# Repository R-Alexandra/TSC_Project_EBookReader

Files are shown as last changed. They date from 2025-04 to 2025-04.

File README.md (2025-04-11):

# TSC_Project_EBookReader - Rădulescu Alexandra

Acest proiect reprezintă un sistem de tip **eBook Reader** bazat pe microcontrolerul **ESP32-C6**, ce integrează module de stocare, afișare, senzori de mediu, alimentare prin baterie și interfețe de conectivitate. Dispozitivul este proiectat pentru un consum energetic scăzut și este compatibil cu multiple tipuri de afișaje E-Ink.

OpenBook_EBookReader_Update

---
## Diagramă Bloc
Diagrama_Bloc

---

## Bill of Materials (BOM)

| Componentă | Link Achiziționare | Link Datasheet |
|---|---|---|
| 112A-TAAR-R03 ATTEND | https://store.comet.srl.ro/Catalogue/Product/43497/ | https://www.snapeda.com/parts/112A-TAAR-R03/Attend/datasheet/ |
| Condensator C0402 | https://ro.mouser.com/c/passive-components/capacitors/ceramic-capacitors/?q=CC0402 | https://componentsearchengine.com/Datasheets/2/CC0402MRX5R5BB106.pdf |
| Condensator Tantalum | https://ro.mouser.com/ProductDetail/KYOCERA-AVX/TAJW107M010RNJ?qs=Wtp%252Bf%2FAeVqIH8v1VxV%252B1Rg%3D%3D | https://ro.mouser.com/datasheet/2/40/TAJ-3165264.pdf |
| CHG_LED | https://ro.mouser.com/ProductDetail/Kingbright/KP-1608SURCK?qs=2JU0tDl2GZ3FuyEWfBV1%2Fg== | https://www.snapeda.com/parts/KP-1608SURCK/Kingbright/datasheet/ |
| USBLC6-2SC6Y | https://ro.mouser.com/ProductDetail/STMicroelectronics/USBLC6-2SC6Y?qs=gNDSiZmRJS%2FOgDexvXkdow%3D%3D | https://ro.mouser.com/datasheet/2/389/usblc6_2sc6y-1852505.pdf |
| SD0805S020S1R0 | https://ro.mouser.com/ProductDetail/KYOCERA-AVX/SD0805S020S1R0?qs=jCA%252BPfw4LHbpkAoSnwrdjw%3D%3D | https://ro.mouser.com/datasheet/2/40/schottky-3165252.pdf |
| MBR0530 | https://ro.mouser.com/ProductDetail/onsemi-Fairchild/MBR0530?qs=VOMQJJE%252BBNniwJKcE3T43Q== | https://ro.mouser.com/datasheet/2/308/MBR0530_D-1810985.pdf |
| PGB1010603MR | https://www.digikey.com/en/products/detail/littelfuse-inc/PGB1010603MR/715755 | https://www.littelfuse.com/assetdocs/pulseguard-esd-suppressors-pgb1-datasheet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 |
| Rezistență R0402 | https://ro.mouser.com/c/passive-components/resistors/smd-resistors-chip-resistors/?case%20code%20-%20in=0402 | https://www.yageo.com/upload/media/product/products/datasheet/rchip/PYu-RC_Group_51_RoHS_L_12.pdf |
| BME680 | https://ro.mouser.com/ProductDetail/Bosch-Sensortec/BME688?qs=IS%252B4QmGtzzqQoVDscqwx3A%3D%3D | https://ro.mouser.com/datasheet/2/783/bst_bme688_fl000-2307034.pdf |
| W25Q512JVEIQ | https://ro.mouser.com/ProductDetail/Winbond/W25Q512JVEIQ?qs=l7cgNqFNU1jw6svr3at6tA%3D%3D | https://ro.mouser.com/datasheet/2/949/Winbond_W25Q512JV_Datasheet-3240039.pdf |
| ESP32-C6-WROOM-1-N8 | https://ro.mouser.com/ProductDetail/Espressif-Systems/ESP32-C6-WROOM-1-N8?qs=8Wlm6%252BaMh8ST02Gmwp74cw%3D%3D | https://ro.mouser.com/datasheet/2/891/Espressif_ESP32_C6_WROOM_1__Datasheet_V0_1_PRELIMI-3239987.pdf |
| DS3231SN# | https://ro.mouser.com/ProductDetail/Analog-Devices-Maxim-Integrated/DS3231SN?qs=1eQvB6Dk1vhUlr8%2FOrV0Fw%3D%3D | https://ro.mouser.com/datasheet/2/609/DS3231-3421123.pdf |
| MAX17048G+T10 | https://ro.mouser.com/ProductDetail/Analog-Devices-Maxim-Integrated/MAX17048G%2bT10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 | https://ro.mouser.com/datasheet/2/609/MAX17048_MAX17049-3469099.pdf |
| MCP73831 | https://ro.mouser.com/ProductDetail/Microchip-Technology/MCP73831T-2ATI-OT?qs=yUQqVecv4qsZbioEUu%252B83g%3D%3D | https://ro.mouser.com/datasheet/2/268/MCP73831_Family_Data_Sheet_DS20001984H-3441711.pdf |
| BD5229G-TR | https://www.digikey.com/en/products/detail/rohm-semiconductor/BD5229G-TR/3663792 | https://fscdn.rohm.com/en/products/databook/datasheet/ic/power/voltage_detector/bd52xxg-e.pdf |
| XC6220A331MR-G | https://ro.mouser.com/ProductDetail/Torex-Semiconductor/XC6220A331MR-G?qs=AsjdqWjXhJ8ZSWznL1J0gg%3D%3D | https://ro.mouser.com/datasheet/2/760/xc6220-3371556.pdf |
| FH34SRJ-24S-0.5SH(99) | https://ro.mouser.com/ProductDetail/Hirose-Connector/FH34SRJ-24S-0.5SH99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 | https://ro.mouser.com/datasheet/2/185/FH34SRJ_24S_0_5SH_99__CL0580_1255_6_99_2DDrawing_0-1615044.pdf |
| USB4110-GF-A | https://ro.mouser.com/ProductDetail/GCT/USB4110-GF-A?qs=KUoIvG%2F9IlYiZvIXQjyJeA%3D%3D | https://ro.mouser.com/datasheet/2/837/GCT_USB4110_Product_Drawing___20k_cycles-3455479.pdf |
| QWIIC_RIGHT_ANGLE | https://ro.mouser.com/ProductDetail/SparkFun/PRT-14417?qs=wd5RIQLrsJhgdz%2FpmZ%2F3GQ== | https://ro.mouser.com/datasheet/2/813/Qwiic_Connector_Datasheet-1223982.pdf |
| Bobină 744043680 | https://ro.mouser.com/ProductDetail/Wurth-Elektronik/744043680?qs=PGXP4M47uW6VkZq%252BkzjrHA%3D%3D | https://www.we-online.com/components/products/datasheet/744043680.pdf |
| PFMF.050.1 | https://ro.mouser.com/ProductDetail/EPCOS-TDK/B72520T0350K062?qs=dEfas%2FXlABIszF52uu7vrg%3D%3D | https://www.tdk-electronics.tdk.com/inf/75/db/CTVS_14/Surge_protection_series.pdf |
| DMG2305UX-7 | https://www.digikey.com/en/products/detail/diodes-incorporated/DMG2305UX-7/4340666 | https://www.diodes.com/assets/Datasheets/DMG2305UX.pdf |
| Si1308EDL-T1-GE3 | https://www.digikey.com/en/products/detail/vishay-siliconix/SI1308EDL-T1-GE3/4876435 | https://www.vishay.com/docs/63399/si1308edl.pdf |
| Solder Jumper (SJ) | https://grabcad.com/library/solder-jumpers-1 | https://grabcad.com/library/solder-jumpers-1 |
| Buton | https://industry.panasonic.com/global/en/products/control/switch/light-touch/number/evqpuj02k | https://industry.panasonic.com/global/en/downloads?tab=catalog&small_g_cd=203&part_no=EVQPUJ02K |
| CPH3225A | https://www.digikey.com/en/products/detail/seiko-instruments/CPH3225A/8692444 | https://mm.digikey.com/Volume0/opasdata/d220001/medias/docus/6537/rev05-CPHCPM.pdf |

---

## Descriere a componentelor și funcționalității hardware

OpenBook_PCB_3D_top_Update

### Microcontroller: ESP32-C6

- Microcontroller RISC-V pe 32 de biți cu suport **Wi-Fi 6** și **Bluetooth 5 Low Energy (BLE)**
- Alimentat la **3.3V**
- Gestionează toate perifericele proiectului
- Oferă multiple interfețe  **GPIO, SPI, I2C, UART**
  - **SPI**(Serial Peripheral Interface): pentru conectare la memoria NOR Flash, cardul SD și afișajul E-Ink
  - **I2C**(Inter-Integrated Circuit): pentru conectare la senzorul BME688, modulul RTC DS3231 și senzorul de nivel baterie MAX17048
  - **GPIO**(General Purpose Input/Output): utilizat pentru semnale de control pentru ecranul E-Ink, butoane și detecție SD
- Are o arhitectură optimizată pentru **consum redus de energie**, ideală pentru aplicații portabile

### Alimentare și protecție

#### Regulator de tensiune LDO

- **XC6206P332MR-G** transformă tensiunea VIN (5V) în 3.3V și  este folosit un tranzistor suplimentar pentru controlul alimentării

#### Controller de încărcare baterie

- **MCP73831** gestionează încărcarea bateriei Li-Po 3.7V cu protecție integrată contra supratensiunii și a curentului excesiv
- LED-uri pentru semnalizare stare de încărcare

#### Monitorizare nivel baterie

- **MAX17048** oferă monitorizare în timp real a stării de încărcare a bateriei 
- Comunică cu ESP32-C6 prin interfața I2C

#### Conector USB-C și protecție ESD

- Conector **USB-C** pentru alimentare și comunicație
- Protecție la descărcări electrostatice realizată prin **PMF0501** și **USBLC6-2SC6Y**, care protejează liniile de alimentare și semnal

## Stocare

### Card microSD

- Conectat la magistrala **SPI**
- Permite stocarea fișierelor eBook și a jurnalelor de sistem
- Linie dedicată pentru **detectare automată** a cardului

### Memorie NOR Flash externă (64MB)

- Chipul **W25Q512JVEIQ** furnizeză memorie nevolatilă pentru firmware și resurse statice
- Conectată la magistrala **SPI**

## Afișaj E-Paper

### Interfață EPD dedicată

- Include toate conexiunile necesare pentru controlul unui ecran E-Ink (**SPI**, semnale de control precum **EPD_BUSY, EPD_DC, EPD_RST** etc).
- Header dedicat EPD cu 20 pini, compatibil cu mai multe modele DE afișaje.

### Circuit de alimentare EPD

- Utilizează un convertor DC-DC și tranzistoare MOSFET pentru a genera tensiunile de alimentare cerute de ecranele E-Ink.

### Selector tip afișaj

- Permite alegerea tipului de ecran conectat, în funcție de compatibilitatea cu semnalele de control.

## Senzor BME680

- Măsoară: **temperatură, umiditate, presiune atmosferică, calitate aer (VOCs)**
- Este conectat prin interfața **I2C** (SDA și SCL)

## Modul RTC (DS3231SN)

- Precizie ridicată pentru a păstra ora și data corectă, chiar și în absența alimentării principale.
- Interfață **I2C** (SDA și SCL)

## Butoane de control

- Buton **RESET**
- Buton **BOOT**
- Buton custom **IO/CHANGE**

## Test Pads și Conectori de extensie

- Sunt prezente **paduri de testare** și debugging 
- Conector **Qwiic/Stemma QT** pentru extinderea rapidă a sistemului cu senzori I2C suplimentari

## Protecție ESD pentru SPI

- Liniile **SPI** sunt protejate împotriva descărcărilor electrostatice

---

## Consum estimativ de energie
Sistemul este proiectat pentru un consum energetic redus, aspect esențial pentru funcționarea pe baterie.

| Componentă | Consum estimativ |
|---|---|
| ESP32-C6 (Wi-Fi activ) | 120 – 150 mA |
| Afișaj EPD | 20 – 40 mA |
| Senzor BME688 | 1 – 2 mA |
| Card SD (scriere/citire)| 50 – 100 mA |
| MAX17048 + RTC DS3231 | < 1 mA |
| **Total (mod activ)** | **~300 mA** |
| **Total (deep sleep)** | **< 10 mA** |

### Estimare autonomie (baterie LiPo 2000mAh):
- **Folosire intensivă**: câteva ore
- **Standby cu afiș static**: zile/săptămâni

---

## Alocarea pinilor ESP32-C6

### 1. Afișaj EPD (e-paper display)

| Pin ESP32-C6 | Funcție | Observație |
|---|---|---|
| IO3 (26) | EPD_BUSY | Verifică dacă ecranul este ocupat |
| IO5 (5) | EPD_DC | Comută între date și comandă |
| IO6 (6) | SCK | Linie de ceas SPI |
| IO7 (7) | MOSI | Transmisie date SPI |
| IO10 (11) | EPD_CS | Selectare chip pentru EPD |
| IO23 (21) | EPD_RST | Resetare ecran |
| IO20 (18) | EPD_3V3_C | Control alimentare 3V3 pentru EPD |

### 2. Card SD

| Pin ESP32-C6 | Funcție | Observație |
|---|---|---|
| IO2 (27) | MISO | Recepție date SPI |
| IO4 (4) | SS_SD | Selectare chip SD |
| IO6 (6) | SCK | Linie de ceas SPI |
| IO7 (7) | MOSI | Transmisie date SPI |

### 3. Memorie Flash NOR

| Pin ESP32-C6 | Funcție | Observație |
|---|---|---|
| IO11 (12) | FLASH_CS | Selectare chip Flash |
| IO2 (27) | MISO | Recepție date SPI |
| IO6 (6) | SCK | Linie de ceas SPI |
| IO7 (7) | MOSI | Transmisie date SPI |

### 4. Magistrală I2C (BME688, RTC DS3231, MAX17048)

| Pin ESP32-C6 | Funcție | Observație |
|---|---|---|
| IO21 (19) | SDA | Linie de date I2C |
| IO22 (20) | SCL | Linie de ceas I2C |
| IO19 (17) | I2C_PW | Activare alimentare senzori I2C |

### 5. RTC (DS3231)

| Pin ESP32-C6 | Funcție | Observație |
|---|---|---|
| IO0 (8) | INT_RTC | Semnal de întrerupere |
| IO1 (9) | 32KHz | Ieșire ceas precis |
| IO18 (16) | RTC_RST | Reset hardware RTC |

### 6. Conectivitate USB

| Pin ESP32-C6 | Funcție | Observație |
|---|---|---|
| IO12 (13) | USB_D- | Comunicație USB |
| IO13 (14) | USB_D+ | Comunicație USB |

### 7. Serială UART 

| Pin ESP32-C6 | Funcție | Observație |
|---|---|---|
| IO16 (25) | TX | Transmisie UART |
| IO17 (24) | RX | Recepție UART |

### 8. Butoane 

| Pin ESP32-C6 | Funcție | Observație |
|---|---|---|
| EN (3) | RESET | Reset general microcontroler |
| IO8 (10) | IO/BOOT | Buton BOOT (pus pe GND la pornire)  |
| IO15 (23) | IO/CHANGE | Buton custom |

### 9. Alimentare și Referință

| Pin ESP32-C6 | Funcție | Observație |
|---|---|---|
| Pin 2 | 3V3 | Alimentare principală |
| Pin 1 | GND | Împământare |

---

## Considerații privind realizarea proiectului
În procesul de realizare a designului hardware am respectat cerințele din ghidurile de proiectare (ERC, DRC, layout) și am încercat să iau decizii care să ofere echilibru între funcționalitate, integrare și respectarea bunelor practici. Amplasarea componentelor am făcut-o atât pe baza documentației oferite (dimensiuni mecanice și recomandări de placement), cât și pentru o rutare cât mai bună, care să reducă interferențele și să faciliteze traseele de alimentare și semnal.

Pentru designul PCB-ului, am folosit DRC-ul oferit pentru verificare și am rezolvat erorile apărute, inclusiv prin ajustarea dimensiunii unor footprint-uri. Am aplicat regulile de rutare pentru traseele de putere și pentru date, evitând unghiurile drepte. Traseele de alimentare au lățimea de 0.3mm, restul traseelor de 0.15mm și am realizat câte un plan de masă atât pentru top cât și pe bottom. Test pad-urile rămase le-am poziționat astfel încât să putem testa rapid anumite componente: 
- lângă header-ul display-ului pentru a testa alimentarea și semnalele de date către ecran;
- lângă ESP32-C6 pentru a verifica semnale critice și pentru debugging.

Am avut în vedere și integrarea finală în ansamblul 3D al carcasei. De aceea, am poziționat conectorii astfel încât să fie accesibili din exterior, iar unele componente au fost ușor translatate pentru a obține o potrivire corectă și o funcționare bună a dispozitivului. De asemenea, am desenat bateria și ecranul folosind dimensiunile mecanice specificate pentru o integrare cât mai bună.

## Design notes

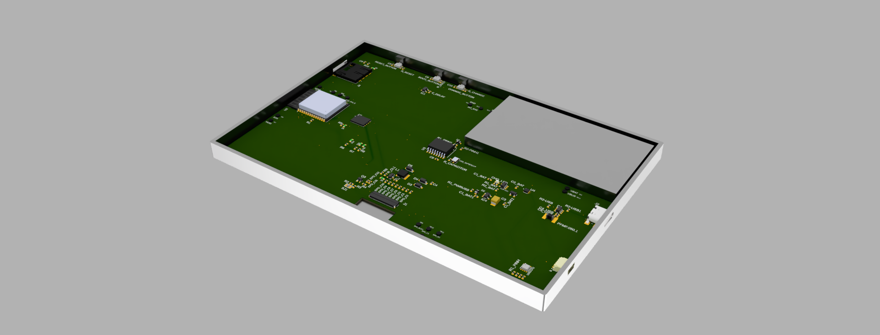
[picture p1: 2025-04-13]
Images/OpenBook_EBookReader_open.png

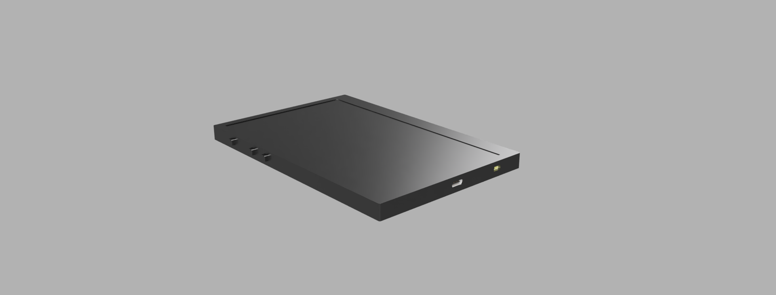
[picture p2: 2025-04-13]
Images/OpenBook_EBookReader_Update.png

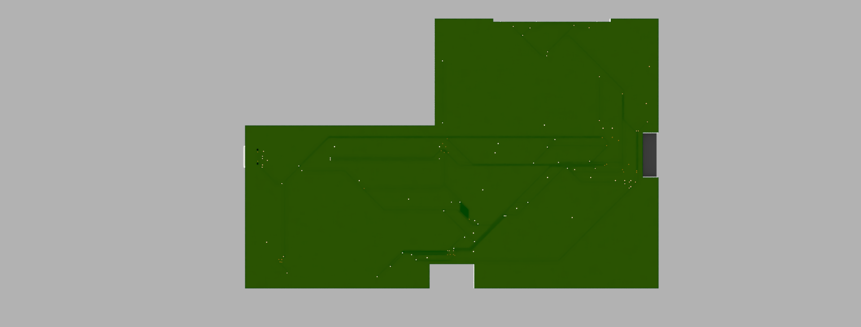
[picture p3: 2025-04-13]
Images/OpenBook_PCB_3D_bottom_Update.PNG

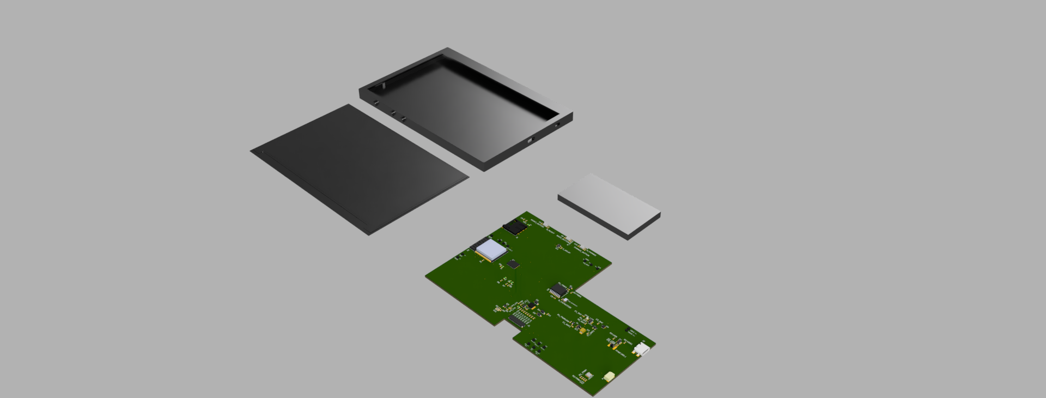
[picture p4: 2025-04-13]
Images/OpenBook_EBookReader_ExplodedView_Update.PNG

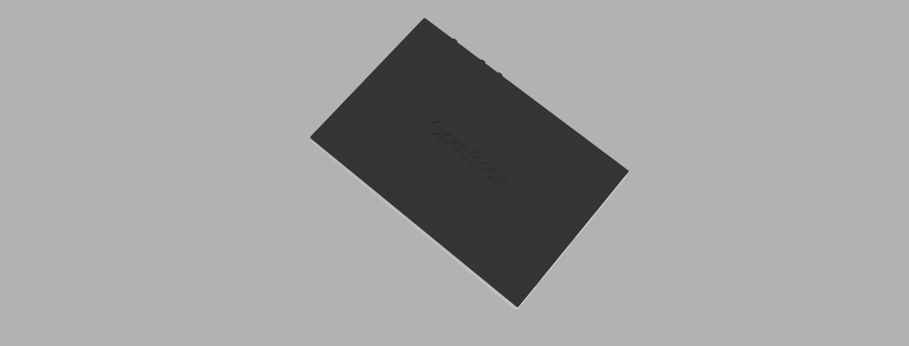
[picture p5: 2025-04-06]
Images/OpenBook_EBookReader2.jpg

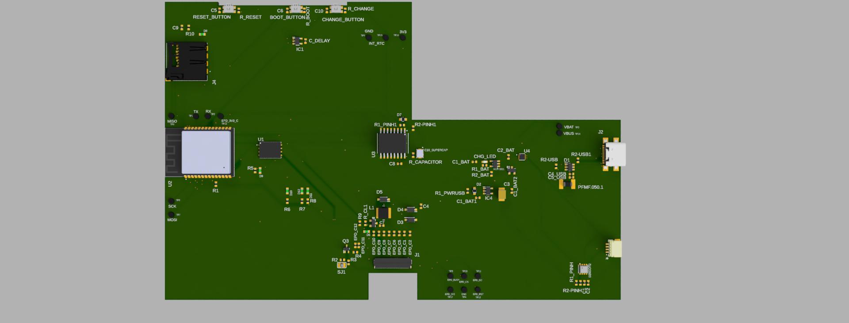
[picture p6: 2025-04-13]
Images/OpenBook_PCB_3D_top_Update.jpg

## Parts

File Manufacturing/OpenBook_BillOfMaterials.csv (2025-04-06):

Qty | Value | Device | Package | Parts | Description | ARROW_PART_NUMBER | ARROW_PRICE-STOCK | AVAILABILITY | CENTROID_NOT_SPECIFIED | CHECK_PRICES | COPYRIGHT | DATASHEET | DESCRIPTION | DIGIKEY_DESCRIPTION | DIGIKEY_PART_NUMBER | HEIGHT | LEAD_FREE | MANUFACTURER_NAME | MANUFACTURER_PART_NUMBER | MF | MFR_NAME | MOUSER_PART_NUMBER | MOUSER_PRICE-STOCK | MOUSER_TESTING_PART_NUMBER | MOUSER_TESTING_PRICE-STOCK | MP | MPN | PACKAGE | POPULARITY | PREFIX | PRICE | PROD_ID | PURCHASE-URL | ROHS | SNAPEDA_LINK | SPICEMODEL | SPICEPREFIX | TEMPERATURE_RANGE_HIGH | TEMPERATURE_RANGE_LOW | TP_SIGNAL_NAME | VALUE
1 |  | ADAFRUIT_LEDCHIP-LED0603 | ADAFRUIT_CHIP-LED0603 | CHG_LED | LED
1 |  | SJ | SJ | SJ1 | SMD solder JUMPER |  |  |  |  |  |  |  |  |  |  |  |  |  |  |  |  |  |  |  |  |  |  |  | 3
1 | 0.1uF/50V | ESP32_WROVER_EAGLE-LTSPICE_CC0402 | ESP32_WROVER_EAGLE-LTSPICE_C0402 | EPD_C5 | CAPACITOR, European symbol |  |  |  |  |  |  |  |  |  |  |  |  |  |  |  |  |  |  |  |  |  |  |  |  |  |  |  |  |  |  | NONE | C
1 | 0.47 | ESP32_WROVER_EAGLE-LTSPICE_RR0402 | ESP32_WROVER_EAGLE-LTSPICE_R0402 | R3 | RESISTOR, European symbol |  |  |  |  |  |  |  |  |  |  |  |  |  |  |  |  |  |  |  |  |  |  |  |  |  |  |  |  |  |  | NONE | R
1 | 100K | ESP32_WROVER_EAGLE-LTSPICE_RR0402 | ESP32_WROVER_EAGLE-LTSPICE_R0402 | R1_PWRUSB | RESISTOR, European symbol |  |  |  |  |  |  |  |  |  |  |  |  |  |  |  |  |  |  |  |  |  |  |  |  |  |  |  |  |  |  | NONE | R
8 | 100nF | ESP32_WROVER_EAGLE-LTSPICE_CC0402 | ESP32_WROVER_EAGLE-LTSPICE_C0402 | C1, C2, C4_USB, C6, C8, C9, C10, C_DELAY | CAPACITOR, European symbol |  |  |  |  |  |  |  |  |  |  |  |  |  |  |  |  |  |  |  |  |  |  |  |  |  |  |  |  |  |  | NONE | C
1 | 100uF TANT | RCL_CPOL-EUCT3528 | RCL_CT3528 | C3 | POLARIZED CAPACITOR, European symbol |  |  |  |  |  |  |  |  |  |  |  |  |  |  |  |  |  |  |  |  |  |  |  | 0 |  |  |  |  |  |  |  | C
16 | 10K | ESP32_WROVER_EAGLE-LTSPICE_RR0402 | ESP32_WROVER_EAGLE-LTSPICE_R0402 | R1, R1_PINH, R1_PINH1, R2-PINH, R2-PINH1, R4, R5, R6, R7, R8, R9, R10, R_BOOT, R_CHANGE, R_CL1, R_RESET | RESISTOR, European symbol |  |  |  |  |  |  |  |  |  |  |  |  |  |  |  |  |  |  |  |  |  |  |  |  |  |  |  |  |  |  | NONE | R
1 | 10uF | ESP32_WROVER_EAGLE-LTSPICE_CC0402 | ESP32_WROVER_EAGLE-LTSPICE_C0402 | C7 | CAPACITOR, European symbol |  |  |  |  |  |  |  |  |  |  |  |  |  |  |  |  |  |  |  |  |  |  |  |  |  |  |  |  |  |  | NONE | C
1 | 112A-TAAR-R03_ATTEND | 112A-TAAR-R03_ATTEND | 112ATAARR03ATTEND | J4 | Micro SD Card Socket, Push-Push Type, Top Mount, SMT, H=1.83mm, 10u |  |  |  |  |  |  |  | Micro SD Card Socket | Push-Push Type | Top Mount | SMT | H=1.83mm | 10u |  |  | 1.9mm |  | ATTEND | 112A-TAAR-R03 ATTEND
1 | 15 | ESP32_WROVER_EAGLE-LTSPICE_RR0402 | ESP32_WROVER_EAGLE-LTSPICE_R0402 | R_CAPACITOR | RESISTOR, European symbol |  |  |  |  |  |  |  |  |  |  |  |  |  |  |  |  |  |  |  |  |  |  |  |  |  |  |  |  |  |  | NONE | R
1 | 1uF | ESP32_WROVER_EAGLE-LTSPICE_CC0402 | ESP32_WROVER_EAGLE-LTSPICE_C0402 | C5 | CAPACITOR, European symbol |  |  |  |  |  |  |  |  |  |  |  |  |  |  |  |  |  |  |  |  |  |  |  |  |  |  |  |  |  |  | NONE | C
9 | 1uF/50V | ESP32_WROVER_EAGLE-LTSPICE_CC0402 | ESP32_WROVER_EAGLE-LTSPICE_C0402 | EPD_C1, EPD_C2, EPD_C6, EPD_C7, EPD_C8, EPD_C9, EPD_C10, EPD_C11, EPD_C12 | CAPACITOR, European symbol |  |  |  |  |  |  |  |  |  |  |  |  |  |  |  |  |  |  |  |  |  |  |  |  |  |  |  |  |  |  | NONE | C
1 | 2.2 | ESP32_WROVER_EAGLE-LTSPICE_RR0402 | ESP32_WROVER_EAGLE-LTSPICE_R0402 | R2 | RESISTOR, European symbol |  |  |  |  |  |  |  |  |  |  |  |  |  |  |  |  |  |  |  |  |  |  |  |  |  |  |  |  |  |  | NONE | R
1 | 200 | ESP32_WROVER_EAGLE-LTSPICE_RR0402 | ESP32_WROVER_EAGLE-LTSPICE_R0402 | R1_BAT | RESISTOR, European symbol |  |  |  |  |  |  |  |  |  |  |  |  |  |  |  |  |  |  |  |  |  |  |  |  |  |  |  |  |  |  | NONE | R
2 | 20V/4.2A/52m?/1.4W | ESP32_WROVER_SPARKFUN-DISCRETESEMI_MOSFET_PCH-DMG2305UX-7 | ESP32_WROVER_SPARKFUN-DISCRETESEMI_SOT23-3 | Q1, Q2 | P-channel MOSFETs |  |  |  |  |  |  |  |  |  |  |  |  |  |  |  |  |  |  |  |  |  |  |  |  |  |  | TRAN-14388 |  |  |  |  |  |  |  |  | 20V/4.2A/52m?/1.4W
1 | 2K | ESP32_WROVER_EAGLE-LTSPICE_RR0402 | ESP32_WROVER_EAGLE-LTSPICE_R0402 | R2_BAT | RESISTOR, European symbol |  |  |  |  |  |  |  |  |  |  |  |  |  |  |  |  |  |  |  |  |  |  |  |  |  |  |  |  |  |  | NONE | R
5 | 4.7uF | ESP32_WROVER_EAGLE-LTSPICE_CC0402 | ESP32_WROVER_EAGLE-LTSPICE_C0402 | C1_BAT, C1_BAT1, C1_BAT2, C2_BAT, C5_USB | CAPACITOR, European symbol |  |  |  |  |  |  |  |  |  |  |  |  |  |  |  |  |  |  |  |  |  |  |  |  |  |  |  |  |  |  | NONE | C
1 | 4.7uF/25V | ESP32_WROVER_EAGLE-LTSPICE_CC0402 | ESP32_WROVER_EAGLE-LTSPICE_C0402 | C4 | CAPACITOR, European symbol |  |  |  |  |  |  |  |  |  |  |  |  |  |  |  |  |  |  |  |  |  |  |  |  |  |  |  |  |  |  | NONE | C
2 | 5k1 | ESP32_WROVER_EAGLE-LTSPICE_RR0402 | ESP32_WROVER_EAGLE-LTSPICE_R0402 | R2-USB, R2-USB1 | RESISTOR, European symbol |  |  |  |  |  |  |  |  |  |  |  |  |  |  |  |  |  |  |  |  |  |  |  |  |  |  |  |  |  |  | NONE | R
1 | 68uH | 744043680IND_4828-WE-TPC_WRE | IND_4828-WE-TPC_WRE | L1 |  |  |  |  |  |  | Copyright (C) 2024 Ultra Librarian. All rights reserved. |  |  |  |  |  |  |  | 744043680 |  | Wurth Electronics
1 | BD5229G-TR | BD5229G-TR | SOT95P280X125-5N | IC1 | Voltage Detector with Adjustable Delay Time: CMOS processes are utilized to develop high precision, low current consumption CMOS reset ICs that allow arbitrary setting of the delay time. The extensive lineup includes both Nch Open Drain and CMOS output types in a wide range of detection voltages (from 2.3V to 6.0V, in 0.1V steps), enabling selection of the ideal solution based on customer requirements. In addition, the entire series is of course both lead-free and RoHS-compliant. |  |  |  |  |  |  |  | Voltage Detector with Adjustable Delay Time: CMOS processes are utilized to develop high precision | low current consumption CMOS reset ICs that allow arbitrary setting of the delay time. The extensive lineup includes both Nch Open Drain and CMOS output types in a wide range of detection voltages (from 2.3V to 6.0V | in 0.1V steps) | enabling selection of the ideal solution based on customer requirements. In addition | the entire series is of course both lead-free and RoHS-compliant. |  |  | 1.25mm |  | ROHM Semiconductor | BD5229G-TR |  |  | 755-BD5229G-TR | https://www.mouser.co.uk/ProductDetail/ROHM-Semiconductor/BD5229G-TR?qs=4kLU8WoGk0vvnhrrYwdszw%3D%3D
1 | BME688 | ESP32_WROVER_BME680_BME680 | ESP32_WROVER_BME680_PSON80P300X300X100-8N | SENSOR2 | Integrated Environmental Unit |  |  | Unavailable |  |  |  |  | Integrated Environmental Unit |  |  |  |  |  |  | Bosch Sensortec |  |  |  |  |  | BME680 |  | LGA-8 Bosch Tools |  |  | None
3 | BUTTON_CUSYOMV1 | BUTTON_CUSYOMV1 | MYBUTTON | BOOT_BUTTON, CHANGE_BUTTON, RESET_BUTTON
1 | CPH3225A | CPH3225A | CAPCP3225X100N | C10_SUPERCAP | Cap 0.011F 3.3V 1210 Flat Check availability |  |  | Not in stock |  | https://www.snapeda.com/parts/CPH3225A/Seiko+Instruments/view-part/?ref=eda |  |  | 11 mF (EDLC) Supercapacitor 3.3 V 1210 (3225 Metric) - - |  |  |  |  |  |  | Seiko Instruments |  |  |  |  |  | CPH3225A |  | 1210 Seiko |  |  | None |  | https://www.snapeda.com/api/url_track_click_mouser/?unipart_id=562593&manufacturer=Seiko Instruments&part_name=CPH3225A&search_term=None |  | https://www.snapeda.com/parts/CPH3225A/Seiko+Instruments/view-part/?ref=snap
1 | DS3231SN# | DS3231SN# | SOIC127P1032X265-16N | U3 | Real Time Clock Serial 16-Pin SOIC W T/R Check availability |  |  | In Stock |  | https://www.snapeda.com/parts/DS3231SN%23/Analog+Devices/view-part/?ref=eda |  |  | Extremely Accurate I2C-Integrated RTC/TCXO/Crystal |  |  |  |  |  |  | Analog Devices |  |  |  |  |  | DS3231SN# |  | SOIC-16 Maxim |  |  | None |  | https://www.snapeda.com/api/url_track_click_mouser/?unipart_id=99048&manufacturer=Analog Devices&part_name=DS3231SN#&search_term=None |  | https://www.snapeda.com/parts/DS3231SN%23/Analog+Devices/view-part/?ref=snap
1 | ESP32-C6-WROOM-1-N8 | ESP32-C6-WROOM-1-N8 | XCVR_ESP32-C6-WROOM-1-N8 | U2 | Check availability |  |  | In Stock |  | https://www.snapeda.com/parts/ESP32-C6-WROOM-1-N8/Espressif+Systems/view-part/?ref=eda |  |  | Multiprotocol Modules ESP32-C6 module | Wi-Fi 6 in 2.4 GHz band | Bluetooth 5 | Zigbee 3.0 and Thread. ESP34-WROOM Compatible - ENGINEERING SAMPLE |  |  |  |  |  |  | Espressif Systems |  |  |  |  |  | ESP32-C6-WROOM-1-N8 |  | None |  |  | None |  |  |  | https://www.snapeda.com/parts/ESP32-C6-WROOM-1-N8/Espressif+Systems/view-part/?ref=snap
1 | ESP32C6_VARISTORCN1812 | ESP32C6_VARISTORCN1812 | ESP32C6_VARISTOR_CT/CN1812 | PFMF.050.1 | VARISTOR |  |  |  |  |  |  |  |  |  |  |  |  |  |  |  |  |  |  |  |  |  |  |  | 0
1 | ESP32_WROVER_AVX---SD0805S020S1R0_AVX_SD0805S020S1R0_0_0AVX_SD0805S020S1R0_0_0 | ESP32_WROVER_AVX---SD0805S020S1R0_AVX_SD0805S020S1R0_0_0AVX_SD0805S020S1R0_0_0 | ESP32_WROVER_AVX---SD0805S020S1R0_AVX_SD0805S020S1R0_0 | D2 | Schottky Barrier Rectifier Diode |  |  |  | No |  |  | http://datasheets.avx.com/schottky.pdf |  | DIODE SCHOTTKY 20V 1A 0805 | 478-7800-1-ND |  | yes |  |  | AVX |  | 581-SD0805S020S1R0 |  |  |  |  |  | 0805 (2012 metric) |  | D |  |  |  | yes |  |  |  | +125°C | -55°C
1 | ESP32_WROVER_SPARKFUN-IC-POWER_MCP73831 | ESP32_WROVER_SPARKFUN-IC-POWER_MCP73831 | ESP32_WROVER_SPARKFUN-IC-POWER_SOT23-5 | MCP73831 | MCP73831T Li-Ion, Li-Pol Controller |  |  |  |  |  |  |  |  |  |  |  |  |  |  |  |  |  |  |  |  |  |  |  |  |  |  | IC-09995
1 | FH34SRJ-24S-0.5SH_99_ | FH34SRJ-24S-0.5SH_99_ | FH34SRJ24S05SH99 | J1 | (0.50mm) Surface Mount, Right Angle |  |  |  |  |  |  |  | 24 Position FFC | FPC Connector Contacts | (0.50mm) Surface Mount | Right Angle |  |  | 1.1mm |  | Hirose | FH34SRJ-24S-0.5SH(99) |  |  | 798-FH34SRJ24S05SH99 | https://www.mouser.co.uk/ProductDetail/Hirose-Connector/FH34SRJ-24S-0.5SH99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
1 | MAX17048G+T10 | MAX17048G+T10 | SON50P200X200X80-9N | U4 | Check availability |  |  | In Stock |  | https://www.snapeda.com/parts/MAX17048G+T10/Analog+Devices/view-part/?ref=eda |  |  | 3µA 1-Cell/2-Cell Fuel Gauge with ModelGauge |  |  |  |  |  |  | Analog Devices |  |  |  |  |  | MAX17048G+T10 |  | TDFN-8 Maxim |  |  | None |  | https://www.snapeda.com/api/url_track_click_mouser/?unipart_id=329239&manufacturer=Analog Devices&part_name=MAX17048G+T10&search_term=None |  | https://www.snapeda.com/parts/MAX17048G+T10/Analog+Devices/view-part/?ref=snap
3 | MBR0530 | MBR0530 | SOD3716X135N | D3, D4, D5 | ON SEMICONDUCTOR - MBR0530 - DIODE, SCHOTTKY, 0.5A, 30V, SOD-123 |  |  | In Stock |  | https://www.snapeda.com/parts/MBR0530/Onsemi/view-part/?ref=eda |  |  | Diode Schottky 30 V 500mA Surface Mount SOD-123 |  |  |  |  |  |  | ON Semiconductor |  |  |  |  |  | MBR0530 |  | SOD-123-2 ON Semiconductor |  |  | None |  | https://www.snapeda.com/api/url_track_click_mouser/?unipart_id=179458&manufacturer=ON Semiconductor&part_name=MBR0530&search_term=None |  | https://www.snapeda.com/parts/MBR0530/Onsemi/view-part/?ref=snap
6 | PGB1010603MR | PGB1010603MR | DIOC1608X36N | D6, D8, D9, D10, D11, D12 | Check availability |  |  | In Stock |  | https://www.snapeda.com/parts/PGB1010603MR/Littelfuse/view-part/?ref=eda |  |  | 150V (Typ) Clamp - Ipp Tvs Diode Surface Mount 0603 (1608 Metric) |  |  |  |  |  |  | Littelfuse Inc. |  |  |  |  |  | PGB1010603MR |  | 0603 Littelfuse Inc. |  |  | None |  | https://www.snapeda.com/api/url_track_click_mouser/?unipart_id=5659453&manufacturer=Littelfuse Inc.&part_name=PGB1010603MR&search_term=None |  | https://www.snapeda.com/parts/PGB1010603MR/Littelfuse/view-part/?ref=snap
1 | QWIIC_RIGHT_ANGLE | QWIIC_CONNECTORJS-1MM | JST04_1MM_RA | J3 | SparkFun I2C Standard Qwiic Connector |  |  |  |  |  |  |  |  |  |  |  |  |  |  |  |  |  |  |  |  |  |  |  |  |  |  | CONN-13694 |  |  |  |  |  |  |  |  | QWIIC_RIGHT_ANGLE
1 | SAMACSYS_PARTS_USB4110-GF-A | SAMACSYS_PARTS_USB4110-GF-A | SAMACSYS_PARTS_USB4110GFA | J2 | CONN USB 2.0 TYPE-C R/A SMT |  |  |  |  |  |  |  | CONN USB 2.0 TYPE-C R/A SMT |  |  | 3.26mm |  | GCT (GLOBAL CONNECTOR TECHNOLOGY) | USB4110-GF-A |  |  | 640-USB4110-GF-A | https://www.mouser.co.uk/ProductDetail/GCT/USB4110-GF-A?qs=KUoIvG%2F9IlYiZvIXQjyJeA%3D%3D
1 | SD0805S020S1R0 | ESP32_WROVER_AVX---SD0805S020S1R0_AVX_SD0805S020S1R0_0_0AVX_SD0805S020S1R0_0_0 | ESP32_WROVER_AVX---SD0805S020S1R0_AVX_SD0805S020S1R0_0 | D7 | Schottky Barrier Rectifier Diode |  |  |  | No |  |  | http://datasheets.avx.com/schottky.pdf |  | DIODE SCHOTTKY 20V 1A 0805 | 478-7800-1-ND |  | yes |  |  | AVX |  | 581-SD0805S020S1R0 |  |  |  |  |  | 0805 (2012 metric) |  | D |  |  |  | yes |  |  |  | +125°C | -55°C
1 | SI1308EDL-T1-GE3 | SI1308EDL-T1-GE3 | SOT65P210X110-3N | Q3 | MOSFET N-Ch 30V 1.5A TrenchFET SC70 Vishay Si1308EDL-T1-GE3 N-channel MOSFET Transistor, 1.5 A, 30 V, 3-Pin SC-70 |  |  | In Stock |  | https://www.snapeda.com/parts/SI1308EDL-T1-GE3/Vishay+Siliconix/view-part/?ref=eda |  |  | Si1308EDL-T1-GE3 N-channel MOSFET Transistor | 1.5 A | 30 V | 3-Pin SC-70 | Siliconix / Vishay SI1308EDL-T1-GE3 |  |  |  |  |  |  | Vishay Siliconix |  |  |  |  |  | SI1308EDL-T1-GE3 |  | SOT-323 Vishay Semiconductor |  |  | None |  | https://www.snapeda.com/api/url_track_click_mouser/?unipart_id=274603&manufacturer=Vishay Siliconix&part_name=SI1308EDL-T1-GE3&search_term=None |  | https://www.snapeda.com/parts/SI1308EDL-T1-GE3/Vishay+Siliconix/view-part/?ref=snap
17 | TPTP20R | TPTP20R | TP20R | TP1, TP2, TP3, TP4, TP5, TP6, TP7, TP8, TP9, TP10, TP11, TP12, TP13, TP14, TP15, TP16, TP17 | Test pad |  |  |  |  |  |  |  |  |  |  |  |  |  |  |  |  |  |  |  |  |  |  |  | 2
1 | USBLC6-2SC6Y | USBLC6-2SC6Y | SOT95P280X145-6N | D1 | Low Cap. ESD Protection Auto SOT-23-6 STMicroelectronics USBLC6-2SC6Y, Dual Uni-Directional TVS Diode Array, 6-Pin SOT-23 |  |  | In Stock |  | https://www.snapeda.com/parts/USBLC6-2SC6Y/STMicroelectronics/view-part/?ref=eda |  |  | 17V Clamp 5A (8/20µs) Ipp Tvs Diode Surface Mount SOT-23-6 |  |  |  |  |  |  | STMicroelectronics |  |  |  |  |  | USBLC6-2SC6Y |  | SOT-23-6 STMicroelectronics |  |  | None |  |  |  | https://www.snapeda.com/parts/USBLC6-2SC6Y/STMicroelectronics/view-part/?ref=snap
1 | W25Q512JVEIQ | W25Q512JVEIQ | SON127P600X800X80-9N | U1 | Check availability |  |  | In Stock |  | https://www.snapeda.com/parts/W25Q512JVEIQ/Winbond+Electronics/view-part/?ref=eda |  |  | FLASH - NOR Memory IC 512Mb (64M x 8) SPI - Quad I/O 133 MHz 8-WSON (8x6) |  |  |  |  |  |  | Winbond Electronics |  |  |  |  |  | W25Q512JVEIQ |  | Package |  |  | None |  |  |  | https://www.snapeda.com/parts/W25Q512JVEIQ/Winbond+Electronics/view-part/?ref=snap
1 | XC6220A331MR-G | XC6220A331MR-G | SOT95P280X120-5N | IC4 | LDO Voltage Regulators |  |  |  |  |  |  |  | LDO Voltage Regulators |  |  | 1.2mm |  | Torex | XC6220A331MR-G |  |  | 865-XC6220A331MR-G | https://www.mouser.co.uk/ProductDetail/Torex-Semiconductor/XC6220A331MR-G?qs=AsjdqWjXhJ8ZSWznL1J0gg%3D%3D

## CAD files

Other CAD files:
Mechanical/OpenBook_EBookReader_updated.f3z

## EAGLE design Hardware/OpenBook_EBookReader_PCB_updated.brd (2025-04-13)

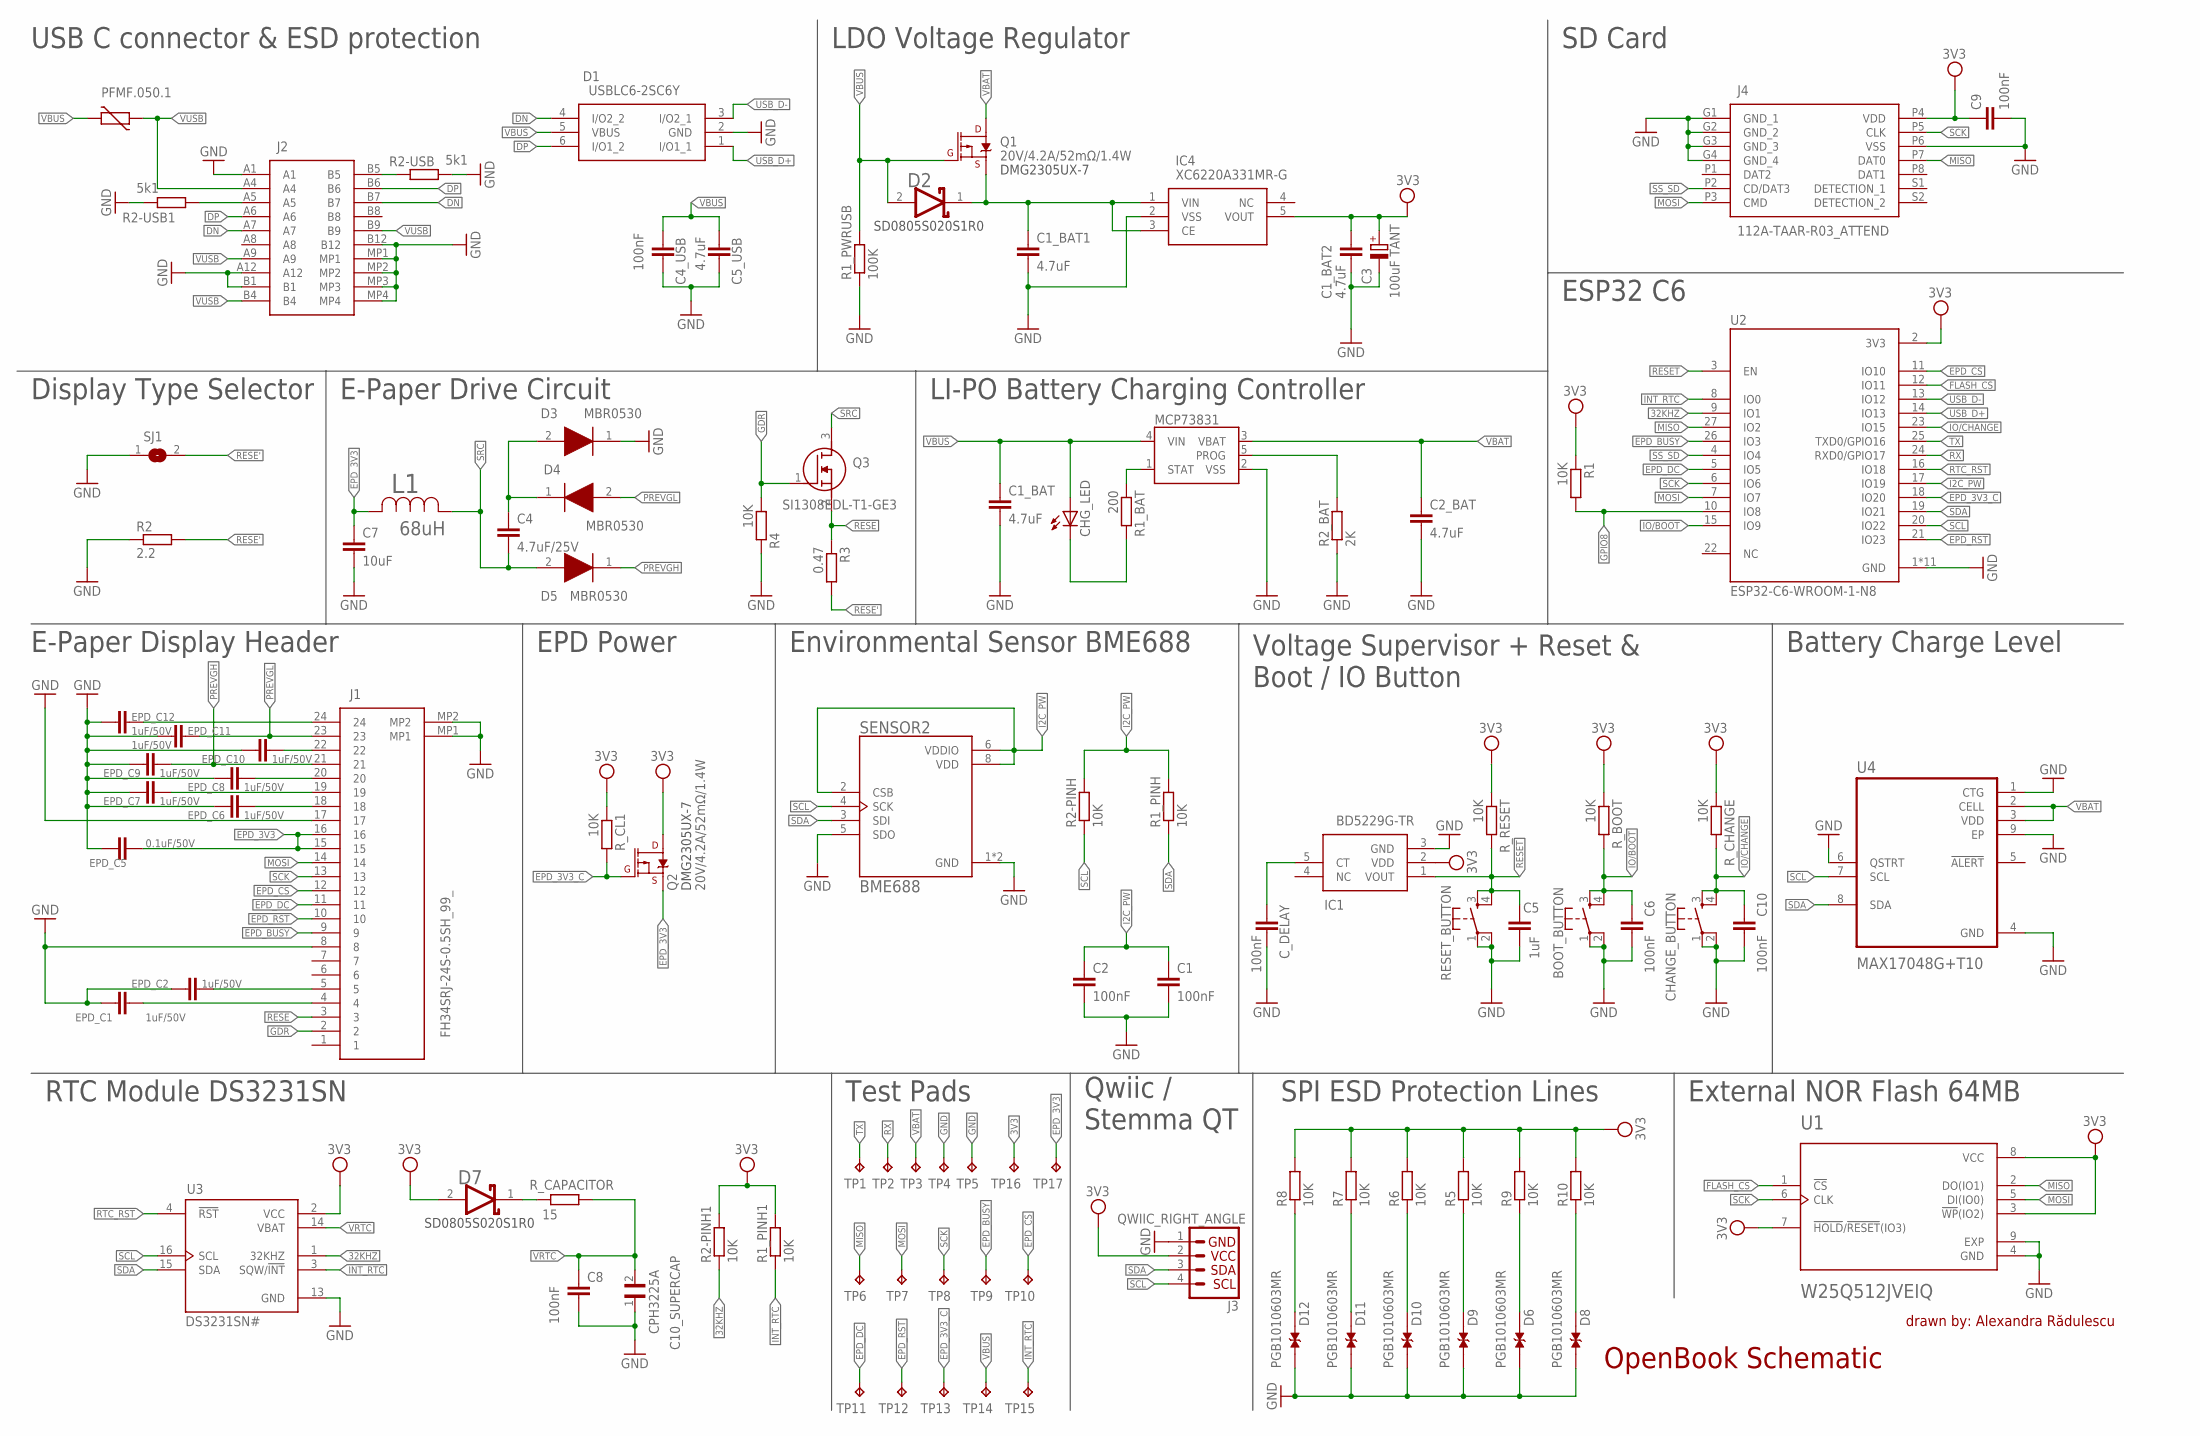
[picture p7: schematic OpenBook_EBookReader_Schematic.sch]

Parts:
BOOT_BUTTON: BUTTON_CUSYOMV1; MYBUTTON
C1, C2, C4_USB, C6, C8, C9, C10: 100nF; ESP32_WROVER_EAGLE-LTSPICE_C0402
C1_BAT, C1_BAT1, C1_BAT2, C2_BAT, C5_USB: 4.7uF; ESP32_WROVER_EAGLE-LTSPICE_C0402
C3: 100uF TANT; RCL_CT3528
C4: 4.7uF/25V; ESP32_WROVER_EAGLE-LTSPICE_C0402
C5: 1uF; ESP32_WROVER_EAGLE-LTSPICE_C0402
C7: 10uF; ESP32_WROVER_EAGLE-LTSPICE_C0402
C10_SUPERCAP: CPH3225A; CAPCP3225X100N
CHANGE_BUTTON: BUTTON_CUSYOMV1; MYBUTTON
CHG_LED: ADAFRUIT_LEDCHIP-LED0603; ADAFRUIT_CHIP-LED0603
C_DELAY: 100nF; ESP32_WROVER_EAGLE-LTSPICE_C0402
D1: USBLC6-2SC6Y; SOT95P280X145-6N
D2: ESP32_WROVER_AVX---SD0805S020S1R0_AVX_SD0805S020S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; ESP32_WROVER_AVX---SD0805S020S1R0_AVX_SD0805S020S1R0_0
D3, D4, D5: MBR0530; SOD3716X135N
D6, D8, D9, D10, D11, D12: PGB1010603MR; DIOC1608X36N
D7: SD0805S020S1R0; ESP32_WROVER_AVX---SD0805S020S1R0_AVX_SD0805S020S1R0_0
EPD_C1, EPD_C2, EPD_C6, EPD_C7, EPD_C8, EPD_C9, EPD_C10, EPD_C11, EPD_C12: 1uF/50V; ESP32_WROVER_EAGLE-LTSPICE_C0402
EPD_C5: 0.1uF/50V; ESP32_WROVER_EAGLE-LTSPICE_C0402
IC1: BD5229G-TR; SOT95P280X125-5N
IC4: XC6220A331MR-G; SOT95P280X120-5N
J1: FH34SRJ-24S-0.5SH_99_; FH34SRJ24S05SH99
J2: SAMACSYS_PARTS_USB4110-GF-A; SAMACSYS_PARTS_USB4110GFA
J3: QWIIC_RIGHT_ANGLE; JST04_1MM_RA
J4: 112A-TAAR-R03_ATTEND; 112ATAARR03ATTEND
L1: 68uH; IND_4828-WE-TPC_WRE
MCP73831: ESP32_WROVER_SPARKFUN-IC-POWER_MCP73831; ESP32_WROVER_SPARKFUN-IC-POWER_SOT23-5
PFMF.050.1: ESP32C6_VARISTORCN1812; ESP32C6_VARISTOR_CT/CN1812
Q1, Q2: 20V/4.2A/52mΩ/1.4W; ESP32_WROVER_SPARKFUN-DISCRETESEMI_SOT23-3
Q3: SI1308EDL-T1-GE3; SOT65P210X110-3N
R1, R1_PINH, R1_PINH1, R2-PINH, R2-PINH1, R4, R5, R6, R7, R8, R9, R10: 10K; ESP32_WROVER_EAGLE-LTSPICE_R0402
R1_BAT: 200; ESP32_WROVER_EAGLE-LTSPICE_R0402
R1_PWRUSB: 100K; ESP32_WROVER_EAGLE-LTSPICE_R0402
R2: 2.2; ESP32_WROVER_EAGLE-LTSPICE_R0402
R2-USB, R2-USB1: 5k1; ESP32_WROVER_EAGLE-LTSPICE_R0402
R2_BAT: 2K; ESP32_WROVER_EAGLE-LTSPICE_R0402
R3: 0.47; ESP32_WROVER_EAGLE-LTSPICE_R0402
RESET_BUTTON: BUTTON_CUSYOMV1; MYBUTTON
R_BOOT: 10K; ESP32_WROVER_EAGLE-LTSPICE_R0402
R_CAPACITOR: 15; ESP32_WROVER_EAGLE-LTSPICE_R0402
R_CHANGE: 10K; ESP32_WROVER_EAGLE-LTSPICE_R0402
R_CL1: 10K; ESP32_WROVER_EAGLE-LTSPICE_R0402
R_RESET: 10K; ESP32_WROVER_EAGLE-LTSPICE_R0402
SENSOR2: BME688; ESP32_WROVER_BME680_PSON80P300X300X100-8N
SJ1: SJ
TP1, TP2, TP3, TP4, TP5, TP6, TP7, TP8, TP9, TP10, TP11, TP12, TP13, TP14, TP15, TP16, TP17: TPTP20R; TP20R
U1: W25Q512JVEIQ; SON127P600X800X80-9N
U2: ESP32-C6-WROOM-1-N8; XCVR_ESP32-C6-WROOM-1-N8
U3: DS3231SN#; SOIC127P1032X265-16N
U4: MAX17048G+T10; SON50P200X200X80-9N

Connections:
3V3: C1_BAT2.1, C3.+, C9.1, D7.2 (ANODE), IC1.2 (VDD), IC4.5 (VOUT), J3.2, J4.P4 (VDD), Q2.3 (D), R1.1, R1_PINH1.2, R2-PINH1.2, R5.2, R6.2, R7.2, R8.2, R9.2, R10.2, R_BOOT.1, R_CHANGE.1, R_CL1.1, R_RESET.1, TP16.TP, U1.3 (!WP!(IO2)), U1.7 (!HOLD!/!RESET!(IO3)), U1.8 (VCC), U2.2 (3V3), U3.2 (VCC)
32KHZ: R2-PINH1.1, U2.9 (IO1), U3.1 (32KHZ)
DN: D1.4 (I/O2_2), J2.A7, J2.B7
DP: D1.6 (I/O1_2), J2.A6, J2.B6
EPD_3V3: C7.1, EPD_C5.1, J1.15, J1.16, L1.2, Q2.2 (S), TP17.TP
EPD_3V3_C: Q2.1 (G), R_CL1.2, TP13.TP, U2.18 (IO20)
EPD_BUSY: J1.9, TP9.TP, U2.26 (IO3)
EPD_CS: J1.12, TP10.TP, U2.11 (IO10)
EPD_DC: J1.11, TP11.TP, U2.5 (IO5)
EPD_RST: J1.10, TP12.TP, U2.21 (IO23)
FLASH_CS: U1.1 (!CS), U2.12 (IO11)
GDR: J1.2, Q3.1 (G), R4.1
GND: BOOT_BUTTON.1, BOOT_BUTTON.2, C1.2, C1_BAT.2, C1_BAT1.2, C1_BAT2.2, C2.2, C2_BAT.2, C3.-, C4_USB.2, C5.2, C5_USB.2, C6.2, C7.2, C8.2, C9.2, C10.2, C10_SUPERCAP.1, CHANGE_BUTTON.1, CHANGE_BUTTON.2, C_DELAY.2, D1.2 (GND), D3.1 (K), D6.1, D8.1, D9.1, D10.1, D11.1, D12.1, EPD_C1.2, EPD_C2.2, EPD_C5.2, EPD_C6.2, EPD_C7.2, EPD_C8.2, EPD_C9.2, EPD_C10.2, EPD_C11.2, EPD_C12.2, IC1.3 (GND), IC4.2 (VSS), J1.8, J1.17, J1.MP1, J1.MP2, J2.A1, J2.A12, J2.B1, J2.B12, J2.MP1, J2.MP2, J2.MP3, J2.MP4, J3.1, J4.G1 (GND_1), J4.G2 (GND_2), J4.G3 (GND_3), J4.G4 (GND_4), J4.P6 (VSS), MCP73831.2 (VSS), R1_PWRUSB.1, R2.1, R2-USB.2, R2-USB1.1, R2_BAT.1, R4.2, RESET_BUTTON.1, RESET_BUTTON.2, SENSOR2.1 (GND), SENSOR2.5 (SDO), SENSOR2.7 (GND), SJ1.1, TP4.TP, TP5.TP, U1.4 (GND), U1.9 (EXP), U2.1 (GND), U2.28 (GND), U2.29_1 (GND), U2.29_2 (GND), U2.29_3 (GND), U2.29_4 (GND), U2.29_5 (GND), U2.29_6 (GND), U2.29_7 (GND), U2.29_8 (GND), U2.29_9 (GND), U3.13 (GND), U4.1 (CTG), U4.4 (GND), U4.6 (QSTRT), U4.9 (EP)
GPIO8: R1.2, U2.10 (IO8)
I2C_PW: C1.1, C2.1, R1_PINH.2, R2-PINH.2, SENSOR2.2 (CSB), SENSOR2.6 (VDDIO), SENSOR2.8 (VDD), U2.17 (IO19)
INT_RTC: R1_PINH1.1, TP15.TP, U2.8 (IO0), U3.3 (SQW/!INT)
IO/BOOT: BOOT_BUTTON.3, BOOT_BUTTON.4, C6.1, R_BOOT.2, U2.15 (IO9)
IO/CHANGE: C10.1, CHANGE_BUTTON.3, CHANGE_BUTTON.4, R_CHANGE.2, U2.23 (IO15)
MISO: J4.P7 (DAT0), TP6.TP, U1.2 (DO(IO1)), U2.27 (IO2)
MOSI: J1.14, J4.P3 (CMD), TP7.TP, U1.5 (DI(IO0)), U2.7 (IO7)
unnamed: C1_BAT1.1, D2.1 (CATHODE), IC4.1 (VIN), IC4.3 (CE), Q1.2 (S)
unnamed: CHG_LED.C, R1_BAT.2
unnamed: MCP73831.1 (STAT), R1_BAT.1
unnamed: EPD_C12.1, J1.24
unnamed: C4.1, D3.2 (A), D4.1 (K)
unnamed: J2.B5, R2-USB.1
unnamed: MCP73831.5 (PROG), R2_BAT.2
unnamed: C_DELAY.1, IC1.5 (CT)
unnamed: EPD_C10.1, J1.22
unnamed: J2.A5, R2-USB1.2
unnamed: D7.1 (CATHODE), R_CAPACITOR.2
unnamed: EPD_C8.1, J1.20
unnamed: EPD_C7.1, J1.19
unnamed: EPD_C6.1, J1.18
unnamed: D12.2, R8.1
unnamed: D11.2, R7.1
unnamed: D10.2, R6.1
unnamed: D9.2, R5.1
unnamed: D6.2, R9.1
unnamed: D8.2, R10.1
unnamed: EPD_C2.1, J1.5
unnamed: EPD_C1.1, J1.4
PREVGH: D5.1 (K), EPD_C9.1, J1.21
PREVGL: D4.2 (A), EPD_C11.1, J1.23
RESE: J1.3, Q3.2 (S), R3.1
RESE': R2.2, R3.2, SJ1.2
RESET: C5.1, IC1.1 (VOUT), RESET_BUTTON.3, RESET_BUTTON.4, R_RESET.2, U2.3 (EN)
RTC_RST: U2.16 (IO18), U3.4 (!RST)
RX: TP2.TP, U2.24 (RXD0/GPIO17)
SCK: J1.13, J4.P5 (CLK), TP8.TP, U1.6 (CLK), U2.6 (IO6)
SCL: J3.4, R2-PINH.1, SENSOR2.4 (SCK), U2.20 (IO22), U3.16 (SCL), U4.7 (SCL)
SDA: J3.3, R1_PINH.1, SENSOR2.3 (SDI), U2.19 (IO21), U3.15 (SDA), U4.8 (SDA)
SRC: C4.2, D5.2 (A), L1.1, Q3.3 (D)
SS_SD: J4.P2 (CD/DAT3), U2.4 (IO4)
TX: TP1.TP, U2.25 (TXD0/GPIO16)
USB_D+: D1.1 (I/O1_1), U2.14 (IO13)
USB_D-: D1.3 (I/O2_1), U2.13 (IO12)
VBAT: C2_BAT.1, MCP73831.3 (VBAT), Q1.3 (D), TP3.TP, U4.2 (CELL), U4.3 (VDD)
VBUS: C1_BAT.1, C4_USB.1, C5_USB.1, CHG_LED.A, D1.5 (VBUS), D2.2 (ANODE), MCP73831.4 (VIN), PFMF.050.1.2, Q1.1 (G), R1_PWRUSB.2, TP14.TP
VRTC: C8.1, C10_SUPERCAP.2, R_CAPACITOR.1, U3.14 (VBAT)
VUSB: J2.A4, J2.A9, J2.B4, J2.B9, PFMF.050.1.1

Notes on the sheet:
USB C connector & ESD protection
Display Type Selector
LDO Voltage Regulator
DMG2305UX-7
SD Card
ESP32 C6
Battery Charge Level
E-Paper Drive Circuit
LI-PO Battery Charging Controller
E-Paper Display Header
EPD Power
Environmental Sensor BME688
Voltage Supervisor + Reset & Boot / IO Button
RTC Module DS3231SN
Test Pads
Qwiic / Stemma QT
SPI ESD Protection Lines
External NOR Flash 64MB
SD0805S020S1R0
OpenBook Schematic
drawn by: Alexandra Rădulescu

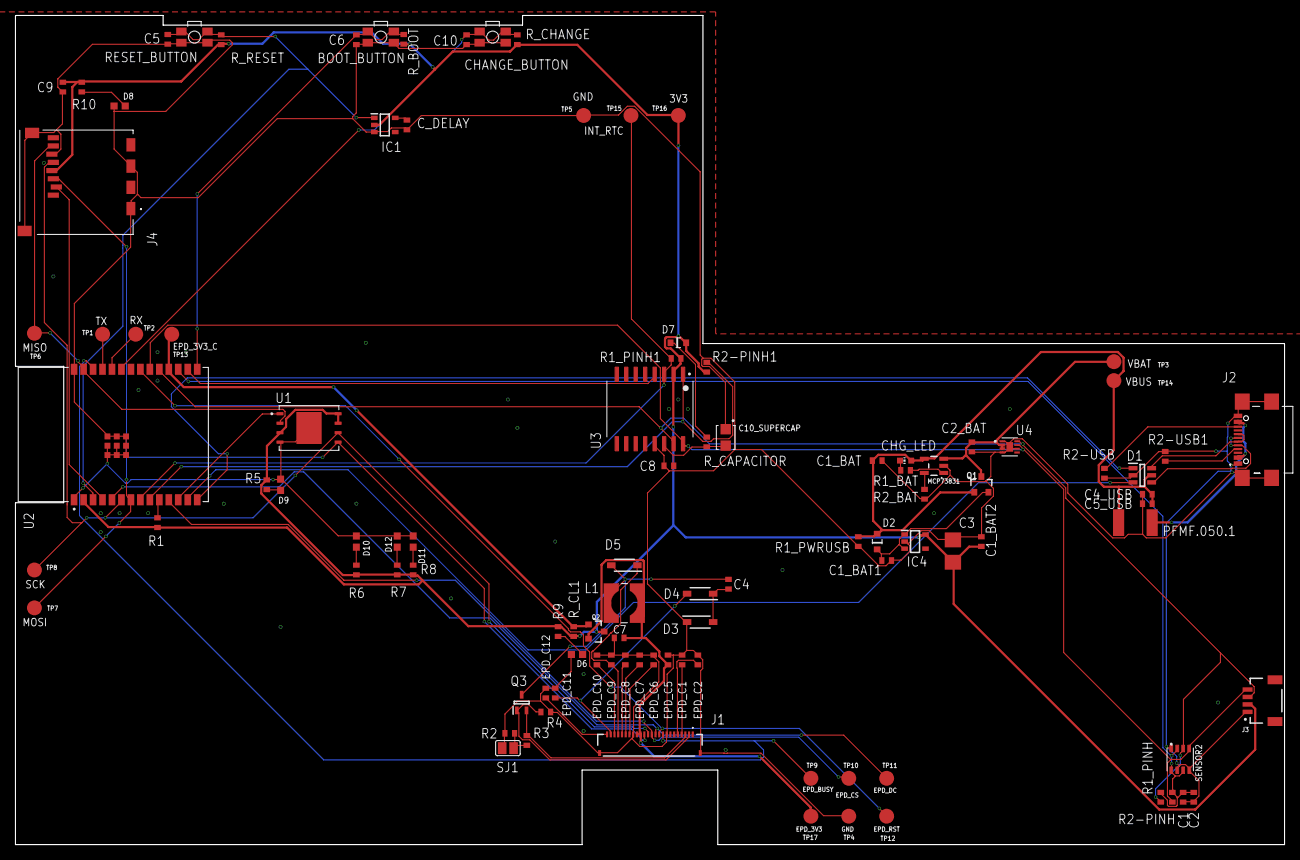
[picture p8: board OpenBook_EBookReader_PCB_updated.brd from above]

Board: 2 copper layers, 170.2 x 111.2 mm, 103 parts (0 on the bottom side), 61 nets.

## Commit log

2025-04-06 Hardware Upload
    [OpenBook_EBookReader_PCB.brd, OpenBook_EBookReader_Schematic.sch]
2025-04-06 Manufacturing Upload
    [OpenBook_BillOfMaterials.csv, OpenBook_front_PickAndPlace.csv]
2025-04-13 Update Hardware
    [OpenBook_EBookReader_PCB_updated.brd]
2025-04-13 Update Mechanical
    [OpenBook_EBookReader_updated.f3z]

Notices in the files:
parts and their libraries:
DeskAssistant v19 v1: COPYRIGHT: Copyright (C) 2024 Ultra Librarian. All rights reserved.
